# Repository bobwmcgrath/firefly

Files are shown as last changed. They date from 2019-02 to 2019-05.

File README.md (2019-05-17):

# firefly
This code has two loops, sense and shine.  In shine, the IR LED blinks on and off really really fast.  In sense the led is off and the sensor (an IR photo transistor) is read at the rate of LED blinking.  Then there is a debouncing algorythem.. or a more apropriatly rebouncing algorythem that makes sure each sensor value alternates being higher or lower than the previouse sensor value.  When this is the case some number of times in a row, another led blinking has been detected.  When blnking is detected the counter that defines the lengeth of the loop is multiplied by 1.1 casuing the sense loop to end sooner untill the LEDs are in sync.  Currently the design works on an arduino at a range of 2' to 4' in a dimly lit room.  

Things to do:

optimize for low power consumption

figure out how well this will work with more than 2 fireflys

more percise timing may be accomplished with interupts

add an asyncronus loop that makes a green LED fade in and out in phase with the other loops

add a function to sleep during the day

design final board

spec final components

add a phase locking mechansism to compensate for clock drift.  

Usefull links:

programing the attiny10

http://www.technoblogy.com/show?1YQY

http://junkplusarduino.blogspot.com/p/attiny10-resources.html

Attiny10 Datasheet

http://ww1.microchip.com/downloads/en/DeviceDoc/atmel-8127-avr-8-bit-microcontroller-attiny4-attiny5-attiny9-attiny10_datasheet.pdf

grant proposal

https://docs.google.com/document/d/1ZPEneeNdc6gHhQVbn35usS5zam0JfSeI3uuNZ7ygSEo/edit?usp=sharing

Photo transistor schematic

https://www.digikey.com/-/media/Images/Article%20Library/TechZone%20Articles/2018/September/How%20to%20Use%20Photodiodes%20and%20Phototransistors%20Most%20Effectivel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

project insperation

https://www.youtube.com/watch?v=ix66tQ93bdU

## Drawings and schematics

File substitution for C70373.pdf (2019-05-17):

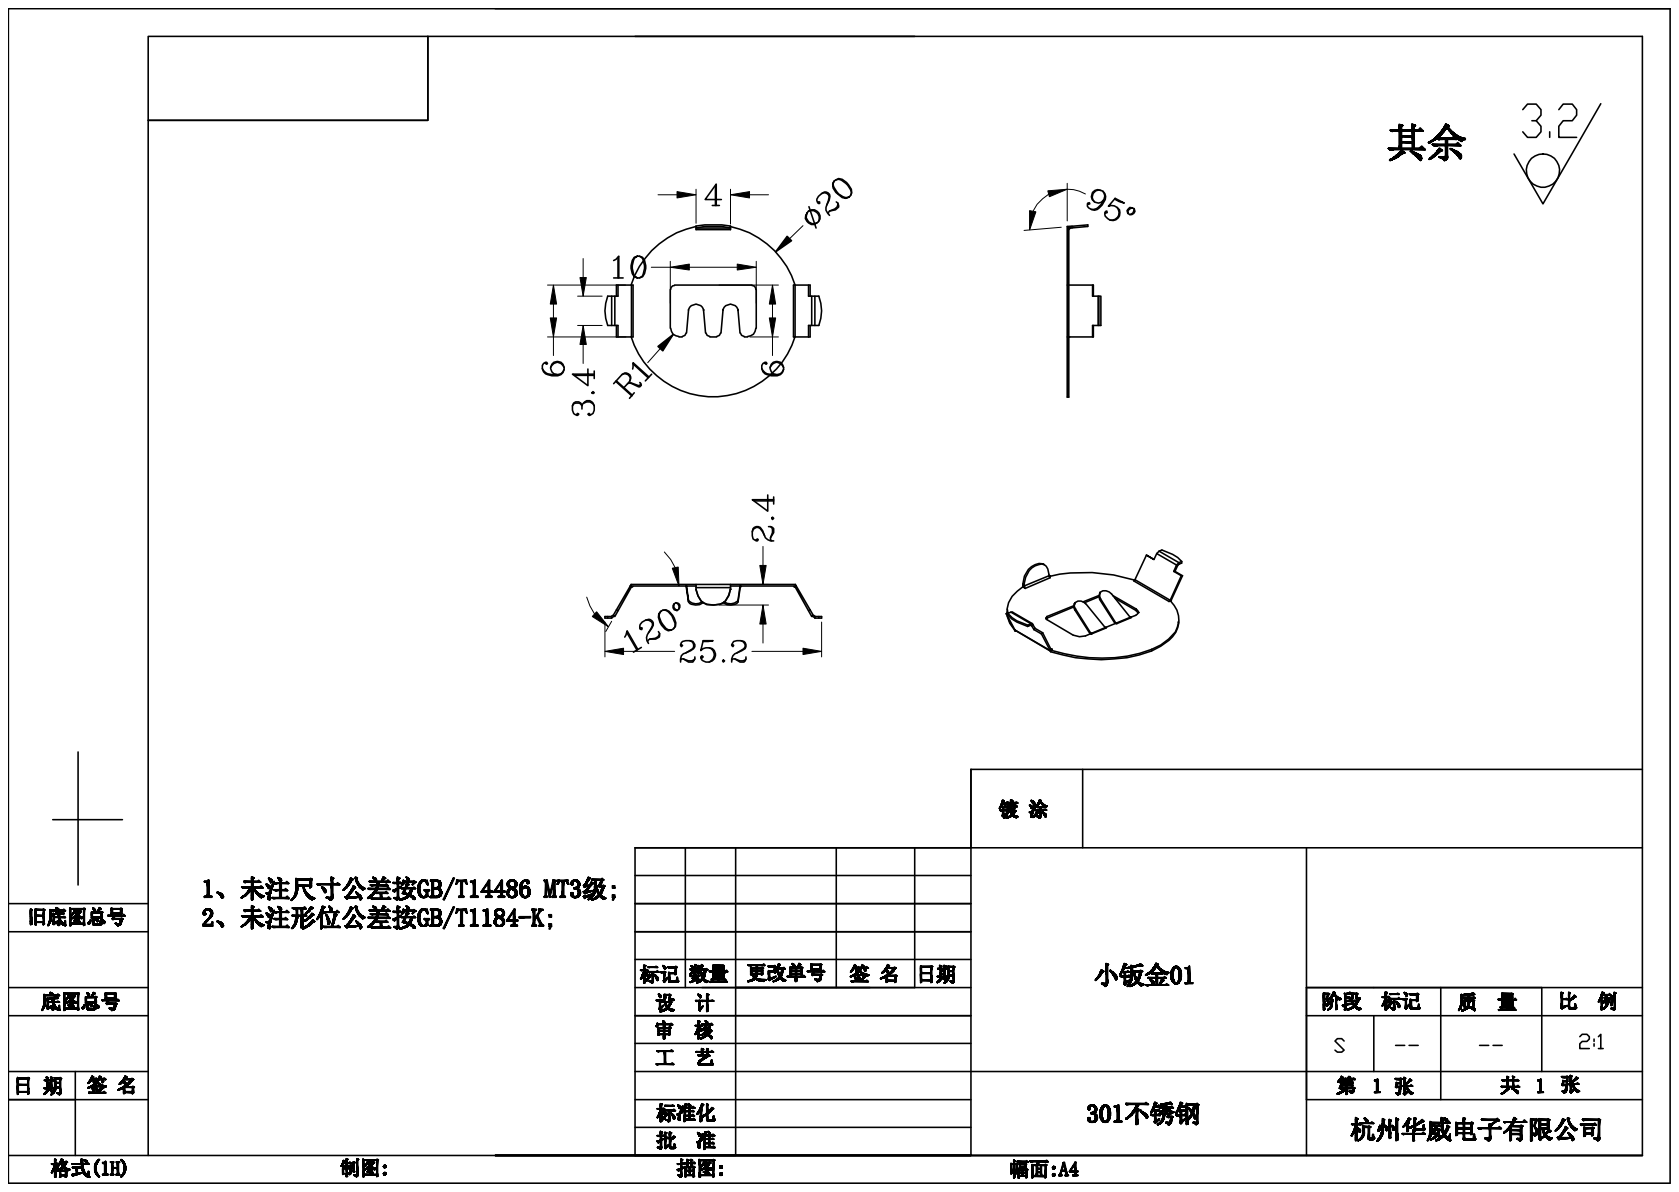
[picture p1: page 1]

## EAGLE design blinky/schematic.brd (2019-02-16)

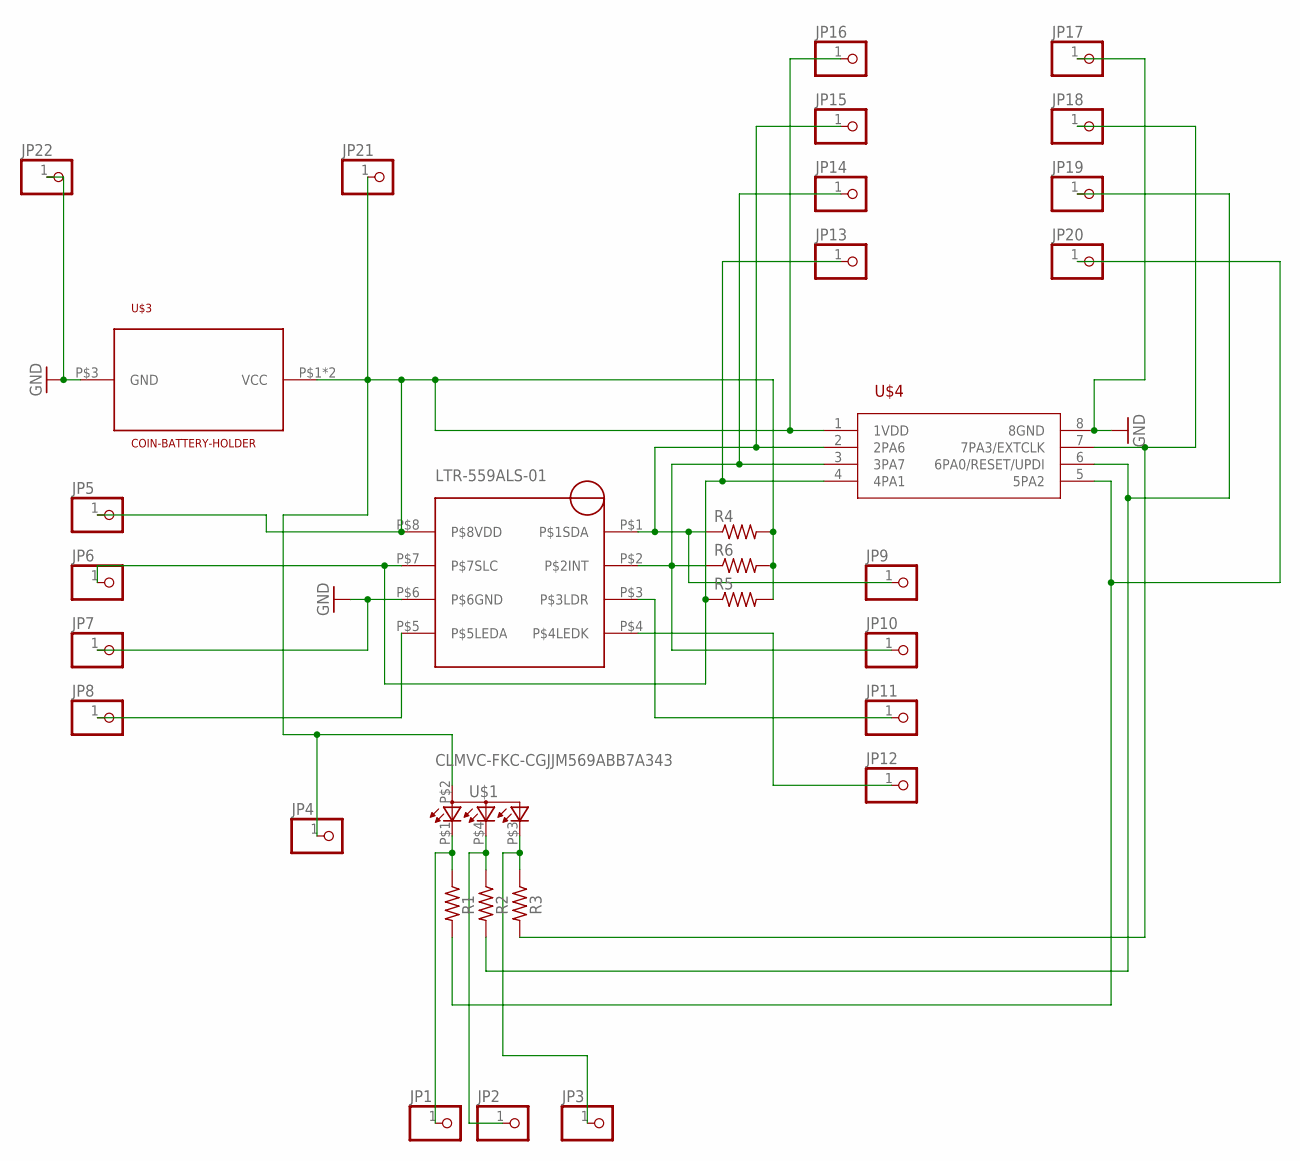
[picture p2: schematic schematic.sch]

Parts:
JP1, JP2, JP3, JP4, JP5, JP6, JP7, JP8, JP9, JP10, JP11, JP12, JP13, JP14, JP15, JP16, JP17, JP18, JP19, JP20, JP21, JP22: PINHD-1X1; 1X01
R1, R2, R3, R4, R5, R6: R-US_R0805; R0805
U$1: CLMVC-FKC-CGJJM569ABB7A343
U$2: LTR-559ALS-01
U$3: COIN-BATTERY-HOLDER; 3034_C
U$4: ATTINY402-SSNR; SOIC127P600X175-8N

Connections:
GND: JP7.1, JP17.1, JP22.1, U$2.P$6 (P$6GND), U$3.P$3 (GND), U$4.8 (8GND)
unnamed: JP3.1, R3.1, U$1.P$3 (CGREEN)
unnamed: JP2.1, R2.1, U$1.P$4 (CBLUE)
unnamed: JP1.1, R1.1, U$1.P$1 (CRED)
unnamed: JP8.1, U$2.P$5 (P$5LEDA)
unnamed: JP18.1, R3.2, U$4.7 (7PA3/EXTCLK)
unnamed: JP19.1, R2.2, U$4.6 (6PA0/RESET/UPDI)
unnamed: JP20.1, R1.2, U$4.5 (5PA2)
unnamed: JP9.1, JP15.1, R4.1, U$2.P$1 (P$1SDA), U$4.2 (2PA6)
unnamed: JP10.1, JP14.1, R6.1, U$2.P$2 (P$2INT), U$4.3 (3PA7)
unnamed: JP6.1, JP13.1, R5.1, U$2.P$7 (P$7SLC), U$4.4 (4PA1)
unnamed: JP4.1, JP5.1, JP16.1, JP21.1, R4.2, R5.2, R6.2, U$1.P$2 (GND), U$2.P$8 (P$8VDD), U$3.P$1 (VCC), U$3.P$2 (VCC), U$4.1 (1VDD)
unnamed: JP11.1, U$2.P$3 (P$3LDR)
unnamed: JP12.1, U$2.P$4 (P$4LEDK)

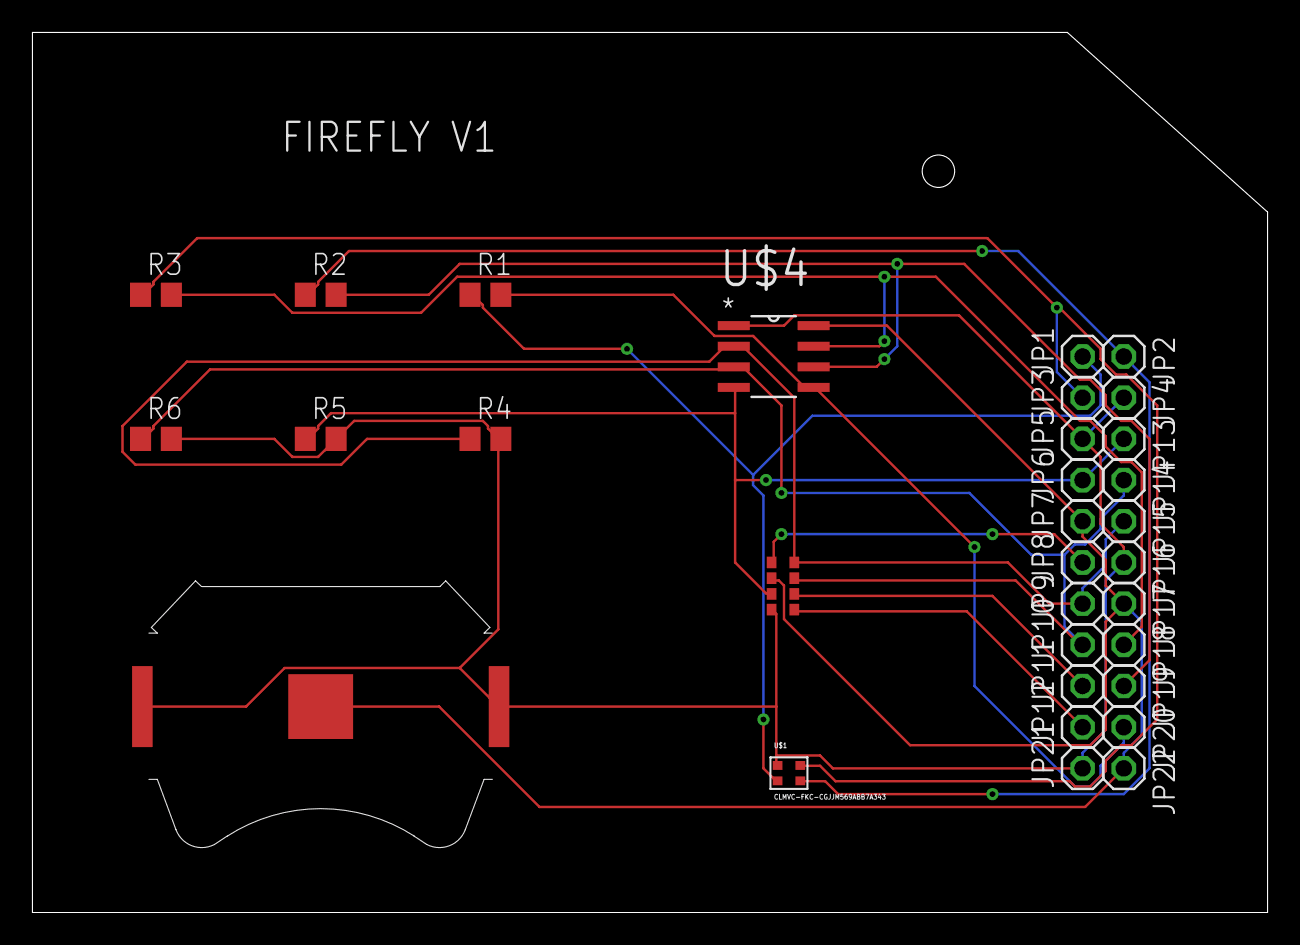
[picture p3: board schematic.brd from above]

Board: 2 copper layers, 76.2 x 54.3 mm, 32 parts (0 on the bottom side), 14 nets.

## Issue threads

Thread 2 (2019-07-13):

Just for reference

seven1240, 2019-07-13:
Just for reference

其余 other
镀涂 coating
小钣金 small plate work
不锈钢 stailess steel

1. 未标尺寸公差按
1. size tolerance default to GB/T11486 MT3 unless marked

2. 未标注形位公差按
2. form and position tolerance default to GB/T1184-K unless marked

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

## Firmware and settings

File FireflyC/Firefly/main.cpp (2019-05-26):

#include <avr/io.h>
#include <stdint.h>
#include <util/delay.h>

int lumens = 1;  //ADC value from the phototransistor
int lastLumens = 1;  // previous lumens value for comparison
int carrier = 1;  // a variable that is 1 if the ADC reading is higher than the previous reading and 0 if it is lower
int lastCarrier = 1; // the previous carrier value for comparison
int carrierCounter = 1; // number of times in a row that the number of lumens reversed direction i.e.  higher or lower
int shineCounter = 1; // number of times through the bloop loop, on and off
int senseCounter1 = 1; // number of times through the sense loop
int senseCounter2 =1; // becuse I cant do floats so this increments one for every 10 senseCounter1s
int dayCounter =1;
//int dayFlag =0;
int pwm=1;

void setup(void){
	//DDRB |= _BV(DDB2); // set as output
	TCCR0A = 2<<COM0A0 | 3<<WGM00; // 10-bit PWM on OC0A (PB0), non-inverting mode
	TCCR0B = 0<<WGM02 | 1<<CS00;   // Divide clock by 1
	DDRB = 0b0101;
}


void shine (void) {
	if (dayCounter<240){
		PORTB |= _BV(PORTB2);
		_delay_ms(4);
		//PORTB |= _BV(PORTB0);// turn on


		PORTB &= ~_BV(PORTB2);
		_delay_ms(4);
		//PORTB &= ~_BV(PORTB0); // turn off

		pwm = 23+2*shineCounter;
		OCR0A = pwm;

		} else {
		_delay_ms(8);
	}
	shineCounter +=1;

	//return shineCounter;

}



void sense () {
	_delay_ms(4);
	lastLumens = lumens;
	lastCarrier=carrier;

	ADMUX = 1<<MUX0;               // ADC0 (PB0)
	ADCSRA = 1<<ADEN | 3<<ADPS0;   // Enable ADC, 125kHz clock
	ADCSRA = ADCSRA | 1<<ADSC;     // Start
	while (ADCSRA & 1<<ADSC);      // Wait while conversion in progress
	lumens = ADCL;               // Copy result to lumens

	
	if (pwm>5)pwm -= 3;
	if (pwm<5)pwm = 0;
	OCR0A = pwm;
	
	senseCounter1 += 1;
	if (lumens > 225) dayCounter+=1;
	if (senseCounter1 % 10 == 0) senseCounter2 += 1;
	if (lumens > lastLumens) carrier = 1;
	else carrier = 0;
	if (carrier != lastCarrier) carrierCounter += 1;
	else carrierCounter=0;
	if (carrierCounter==8) {
		senseCounter1 += senseCounter2; // this is the multiplier that modulates the phase variance
		dayCounter=0;}	
	
	
	
	
	//return senseCounter1;
}

void loop (void) {
	//shine();
	//pwm = 0;
	while(shineCounter <125) shine(); // blink
	dayCounter=0;
	//sense();
	while (senseCounter1<250) sense();
	//if (dayCounter<991) dayFlag=0;
	//if (dayCounter>990) dayFlag=1;
	//shine(); // restart blinking loop
	//}
	//else
	
	shineCounter = 0;
	senseCounter1 = 0;
	carrierCounter=0;
	senseCounter2=0;

	//return dayFlag;
}

int main(void) {
	setup();
	for(;;) loop();
}

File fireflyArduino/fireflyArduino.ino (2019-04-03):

#include <Wire.h>
#include <avr/io.h>
#include <util/delay.h>
 
#define BLINK_DELAY_MS 10

long us = 1;
int lumens = 1;
int lastLumens = 1;
int carrier = 1;
int lastCarrier = 1; 
int carrierCounter = 1;
int blinkCounter = 1;
int senseCounter = 1;


void setup(void) {
   DDRB |= _BV(DDB5);
  //Serial.begin(9600);
}

void loop (void) {
  sense();  // read the value of the sensor
  shine();  // blink the carier frequency
}

void sense (void) {
  lastLumens = lumens;
  lastCarrier=carrier; 
  lux();
  if (lumens > lastLumens) carrier = 1;
  else carrier = 0;
  if (carrier != lastCarrier) carrierCounter+=1;
  else carrierCounter=0;
  if (carrierCounter==5) senseCounter *= 1.1; // this is the multiplier that modulates the phase variance
  if (senseCounter<100) sense();
  }


void lux() {
  _delay_ms(BLINK_DELAY_MS);
  lumens = (analogRead(A0)/4);
  senseCounter += 1;
  //print();
  
}

void shine (void) {
  blinkCounter +=1;
  //print();
  if (blinkCounter <50) { //run loop for 1 second
    bloop(); // blink on 10ms and off 10ms
    shine(); // restart blinking loop
    }
  else {blinkCounter = 0; senseCounter = 0; 
  carrierCounter=0;} // set counters back to zero and restart main loop
  
}

int bloop (void){
 /* set pin 5 of PORTB for output*/
 
  /* set pin 5 high to turn led on */
  PORTB |= _BV(PORTB5);
  _delay_ms(BLINK_DELAY_MS);
 
  /* set pin 5 low to turn led off */
  PORTB &= ~_BV(PORTB5);
  _delay_ms(BLINK_DELAY_MS);
}

void print(void){
  Serial.print(lumens);
  //Serial.print("  ");
  //Serial.print(senseCounter);
  //Serial.print("  ");
  //Serial.print(blinkCounter);
  //Serial.print(" ");
  //Serial.print(carrierCounter);
  Serial.println(" ");
}

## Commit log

2019-02-16 added EAGLE files and readme
    [schematic.brd, schematic.sch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]
2019-04-03 First draft C code for the ATTiny10, examples, and a programmer using arduino
    one variable does not like to be higher than 11
2019-04-03 Old code for the flora sensor on arduino
2019-04-03 Working arduino code with a photo transistor and an IR LED
    Using the serial out put completely breaks the timing.
2019-05-03 fixed reference error in daytime detection
    [main.cpp]
2019-05-03 Added a whole lot of code to try to correct for clock drift. By commenting out line 186 (fix_delay in the main loop), we avoid actually using the code, and the memory it takes up, but can see if ever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
    [main.cpp]
2019-05-17 Does anybody read Chinese?
    For various reasons I would like to source this sub 2 cent battery holder, but I don't know and Chinese.
2019-05-19 faster loop, daytime detection
    reverted from previous
    [main.cpp]
2019-05-19 added dayFlag and fade
    the ir LED fades wether in bright light of not, and the green LED does nothing weather in bright light or not
2019-05-19 fixed shine() - you were returning a global variable
    [main.cpp]
2019-05-25 changed to 4ms cycle
    the sensor is only so fast
